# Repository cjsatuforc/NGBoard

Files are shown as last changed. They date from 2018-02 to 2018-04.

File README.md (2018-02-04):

# NGBoard
Next generation 3d printer controller board
## TODO
* Development
  * PCB Layout
  * BOM/Parts list
  * Switching regulator test
* Production
  * Software
  * Testing
* Profit

## Features
* 32 bit microcontroller (STM32F401VET)
* Trinamic tmc2130 drivers
* Raspberry pi/orange pi connector
* 12V or 24V 
* Direct connect inductive sensor

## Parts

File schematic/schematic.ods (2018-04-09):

Source: | /media/data/Git/NGBoard/schematic/schematic.sch
Date: | Sun 04 Feb 2018 08:46:15 PM CET
Tool: | Eeschema 4.0.7+dfsg1-1
Generator: | /usr/lib/kicad/plugins/bom_csv_grouped_by_value_with_fp.py
Component Count: | 263
Ref | Qnty | Value | RS | Price |  | Cmp name | Footprint | Description | Vendor
C1, C9, C7, C10, C14, C11, C12, C23, C21, C24, C28, C25, C26, C37, C35, C38, C42, C39, C40, C51, C49, C52, C56, C53, C54, C63, C66, C70, C62, C65, C71, C64, C67, C75, C78, C76, C79, C77, C80, C93, C94, C95, C96, C97, C98, C99, C106, | 47 | 100nF | 135-8345 | 0.005 | 0.235 | C | Capacitors_SMD:C_0603 | Unpolarized capacitor
C2, C3, C84, | 3 | 18pF | 652-0263 | 0.031 | 0.093 | C | Capacitors_SMD:C_0603 | Unpolarized capacitor
C4, C5, | 2 | 2.2uF | 798-4649 | 0.039 | 0.078 | C | Capacitors_SMD:C_0805 | Unpolarized capacitor
C6, C20, C34, C48, | 4 | 4.7uF | 798-4668 | 0.041 | 0.164 | C | Capacitors_SMD:C_0805 | Unpolarized capacitor
C8, C22, C36, C50, | 4 | 470nF | 652-0904 | 0.029 | 0.116 | C | Capacitors_SMD:C_0603 | Unpolarized capacitor
C13, C27, C41, C55, | 4 | 22n | 698-3276 | 0.031 | 0.124 | C | Capacitors_SMD:C_0603 | Unpolarized capacitor
C15, C29, C43, C57, C69, C68, | 6 | 100uF | 737-9684 | 0.212 | 1.272 | CP | Capacitors_SMD:CP_Elec_8x10 | Polarised capacitor
C16, C17, C19, C18, C30, C31, C33, C32, C44, C45, C47, C46, C58, C59, C61, C60, | 16 | 1nF | 135-6542 | 0.007 | 0.112 | C | Capacitors_SMD:C_0603 | Unpolarized capacitor
C72, C73, C74, | 3 | 10uF | 885-1890 | 0.13 | 0.39 | C | Capacitors_SMD:C_1206 | Unpolarized capacitor
C81, C82, C83, | 3 | 6800pF | 135-6555 | 0.007 | 0.021 | C | Capacitors_SMD:C_0603 | Unpolarized capacitor
C85, C86, | 2 | 100pF | 264-4523 | 0.022 | 0.044 | C | Capacitors_SMD:C_0603 | Unpolarized capacitor
C87, C90, C88, C91, C89, C92, | 6 | 22uF | 885-1887 | 0.165 | 0.99 | C | Capacitors_SMD:C_1206 | Unpolarized capacitor
C100, C103, C101, C104, C102, C105, | 6 | 1uF | 456-8308 | 0.012 | 0.072 | C | Capacitors_SMD:C_0805 | Unpolarized capacitor
D3, D2, D1, | 3 | SMAJ24A | 748-5161 | 0.105 | 0.315 | D_Schottky | Diodes_SMD:D_SMA | Schottky diode
D4, D5, | 2 | SK310A | 652-6104 | 0.147 | 0.294 | D_Schottky | Diodes_SMD:D_SMA | Schottky diode
D8, D9, D6, D7, | 4 | LED | 692-1170 | 0.037 | 0.148 | LED | LEDs:LED_0805 | LED generic
D10, D11, D15, D13, D14, D12, | 6 | BAT54SW | 380-1216 | 0.08 | 0.48 | D_Schottky_x2_Serial_AKC | TO_SOT_Packages_SMD:SOT-323_SC-70 | Dual schottky diode
D16, | 1 | 3.3V | 687-8250 | 0.087 | 0.087 | D_Zener | Diodes_SMD:D_SOD-123 | Zener Diode
D17, D18, D19, | 3 | D | 700-0861 | 0.029 | 0.087 | D | Diodes_SMD:D_MiniMELF | Diode
F1, | 1 | 15A | 167-6068 | 0.91 | 0.91 | Fuse | Fuse_Holders_and_Fuses:BladeFuse-CarType | Fuse, generic
F3, F2, | 2 | 5A | 167-6068 | 0.91 | 1.82 | Fuse | Fuse_Holders_and_Fuses:BladeFuse-CarType | Fuse, generic
J1, J2, J3, J5, J4, J17, | 6 | Conn_01x04 |  |  | 0 | Conn_01x04 | Socket_Strips:Socket_Strip_Straight_1x04_Pitch2.54mm | Generic connector, single row, 01x04
J6, | 1 | Conn_01x06 | 897-0711 | 0.648 | 0.648 | Conn_01x06 | TerminalBlock_Phoenix:TerminalBlock_Phoenix_MKDS1.5-6pol | Generic connector, single row, 01x06
J7, | 1 | Conn_01x03 |  |  | 0 | Conn_01x03 | Socket_Strips:Socket_Strip_Straight_1x03_Pitch2.54mm | Generic connector, single row, 01x03
J8, | 1 | Screw_Terminal_01x02 | 425-8720 | 0.202 | 0.202 | Screw_Terminal_01x02 | TerminalBlock_Phoenix:TerminalBlock_Phoenix_MKDS1.5-2pol | Generic screw terminal, single row, 01x02
J9, J10, | 2 | Conn_01x03 | 483-8477 | 0.193 | 0.386 | Conn_01x03 | Sockets_MOLEX_KK-System:Socket_MOLEX-KK-RM2-54mm_Lock_3pin_straight | Generic connector, single row, 01x03
J11, J12, J13, J14, J15, J16, | 6 | Conn_01x02 |  |  | 0 | Conn_01x02 | Socket_Strips:Socket_Strip_Straight_1x02_Pitch2.54mm | Generic connector, single row, 01x02
J18, | 1 | Conn_02x13_Odd_Even |  |  | 0 | Conn_02x13_Odd_Even | Socket_Strips:Socket_Strip_Straight_2x13_Pitch2.54mm | Generic connector, double row, 02x13, odd/even pin numbering scheme (row 1 odd numbers, row 2 even numbers)
J20, J19, | 2 | Conn_02x05_Odd_Even |  |  | 0 | Conn_02x05_Odd_Even | Connectors:IDC_Header_Straight_10pins | Generic connector, double row, 02x05, odd/even pin numbering scheme (row 1 odd numbers, row 2 even numbers)
J21, | 1 | Conn_02x05_Odd_Even |  |  | 0 | Conn_02x05_Odd_Even | Pin_Headers:Pin_Header_Straight_2x05_Pitch2.54mm | Generic connector, double row, 02x05, odd/even pin numbering scheme (row 1 odd numbers, row 2 even numbers)
L1, L2, L4, L3, L5, L6, L8, L7, L9, L10, L12, L11, L13, L14, L16, L15, | 16 | 120R | 747-4710 | 0.031 | 0.496 | Ferrite_Bead_Small | Inductors_SMD:L_0603 | Ferrite bead, small symbol
L18, L17, | 2 | 60R | 188-8665 | 0.203 | 0.406 | L_Core_Ferrite | Inductors_SMD:L_1806 | Inductor with Ferrite Core
L19, | 1 | 4.7uH | 743-5116 | 0.282 | 0.282 | L | Inductors_SMD_GITHUB:L_Wuerth_HCM-7070 | Inductor
L20, L21, | 2 | 3.3uH | 743-5107 | 0.271 | 0.542 | L | Inductors_SMD_GITHUB:L_Wuerth_HCM-7070 | Inductor
MK1, MK3, MK2, MK4, | 4 | Mounting_Hole | N/A | 0 | 0 | Mounting_Hole | Mounting_Holes:MountingHole_3.2mm_M3 | Mounting Hole without connection
Q1, Q2, | 2 | PSMN1R7-30YL | 798-2912 | 0.6 | 1.2 | PSMN1 | TO_SOT_Packages_SMD:SOT-669_LFPAK_ThermalVias-1 | Transistor N-MOSFET (general)
Q3, Q4, | 2 | NCV8402 | 807-9956 | 0.41 | 0.82 | Q_NMOS_GDSD | TO_SOT_Packages_SMD:SOT-223 | Transistor N-MOSFETwith substrate diode, drain connected to mounting plane (general)
R1, R2, R4, R3, R8, R7, R12, R11, R16, R15, R26, R27, R58, R59, R60, R65, R72, R73, R74, | 19 | 10K | 125-1173 | 0.015 | 0.285 | R | Resistors_SMD:R_0603 | Resistor
R5, R6, R9, R10, R13, R14, R17, R18, | 8 | 0.22 | 740-9173 | 0.138 | 1.104 | R | Resistors_SMD:R_1206 | Resistor
R19, | 1 | 82K | 679-0737 | 0.024 | 0.024 | R | Resistors_SMD:R_0603 | Resistor
R20, R21, | 2 | 24K | 679-0046 | 0.024 | 0.048 | R | Resistors_SMD:R_0603 | Resistor
R22, | 1 | 430K | 679-0374 | 0.015 | 0.015 | R | Resistors_SMD:R_0603 | Resistor
R23, R24, | 2 | 75K | 810-2328 | 0.032 | 0.064 | R | Resistors_SMD:R_0603 | Resistor
R25, | 1 | 15K | 213-2430 | 0.016 | 0.016 | R | Resistors_SMD:R_0603 | Resistor
R34, R35, R28, R29, R55, R56, R57, R64, | 8 | 100 | 901-3525 | 0.004 | 0.032 | R | Resistors_SMD:R_0603 | Resistor
R36, R37, R30, R31, | 4 | 100K | 740-8811 | 0.026 | 0.104 | R | Resistors_SMD:R_0603 | Resistor
R38, R44, R39, R45, R32, R33, | 6 | 1.8K | 901-3569 | 0.004 | 0.024 | R | Resistors_SMD:R_0603 | Resistor
R40, R42, R41, R43, | 4 | 1K | 213-2266 | 0.008 | 0.032 | R | Resistors_SMD:R_0603 | Resistor
R46, R49, R47, R50, R48, R51, R61, R62, | 8 | 2K37 | 679-0131 | 0.016 | 0.128 | R | Resistors_SMD:R_0603 | Resistor
R52, R53, R54, R63, | 4 | 4.7K | 901-3581 | 0.004 | 0.016 | R | Resistors_SMD:R_0603 | Resistor
R66, R69, R67, R70, R68, R71, | 6 | 1.6K | 873-9309 | 0.024 | 0.144 | R | Resistors_SMD:R_0603 | Resistor
SW1, | 1 | SW_Push_Dual | 135-9534 | 0.105 | 0.105 | SW_Push_Dual | Buttons_Switches_THT:SW_TH_Tactile_Omron_B3F-10xx | Push button switch, generic, symbol, four pins
SW2, | 1 | SW_DIP_x03 | 161-4064 | 0.253 | 0.253 | SW_DIP_x03 | Buttons_Switches_THT:SW_DIP_x3_W7.62mm_Slide | 3x DIP Switch, Single Pole Single Throw (SPST) switch, small symbol
U1, | 1 | STM32F401VETx | 497-17430-ND | 6.16 | 6.16 | STM32F401VETx | Housings_QFP:TQFP-100_14x14mm_Pitch0.5mm | Core: ARM Cortex-M4 Package: LQFP100 Flash: 384KB Ram: 96KB Frequency: 84MHz Voltage: 1.7..3.6V IO-pins: 81
U2, U3, U4, U5, | 4 | TMC2130 | 1460-1186-1-ND | 3.869 | 15.476 | TMC2130 | tmc2130:TQFP-48-1EP_7x7mm_Pitch0.5mm | Driver for two-phase stepper motors with external mosfet
U6, U7, U8, | 3 | BD9E302EFJ | 128-8893 | 0.778 | 2.334 | BD9E302EFJ | HTSOP-J8:SOIC-8
Y1, | 1 | Crystal_GND24 | 904-7437 | 0.31 | 0.31 | Crystal_GND24 | Crystals:Crystal_SMD_SeikoEpson_FA238-4pin_3.2x2.5mm_HandSoldering | Four pin crystal (GND on pins 2 and 4), e.g. in SMD package
 |  |  |  | Total | 36.8272
 |  |  |  | Total + Tax | 44.560912

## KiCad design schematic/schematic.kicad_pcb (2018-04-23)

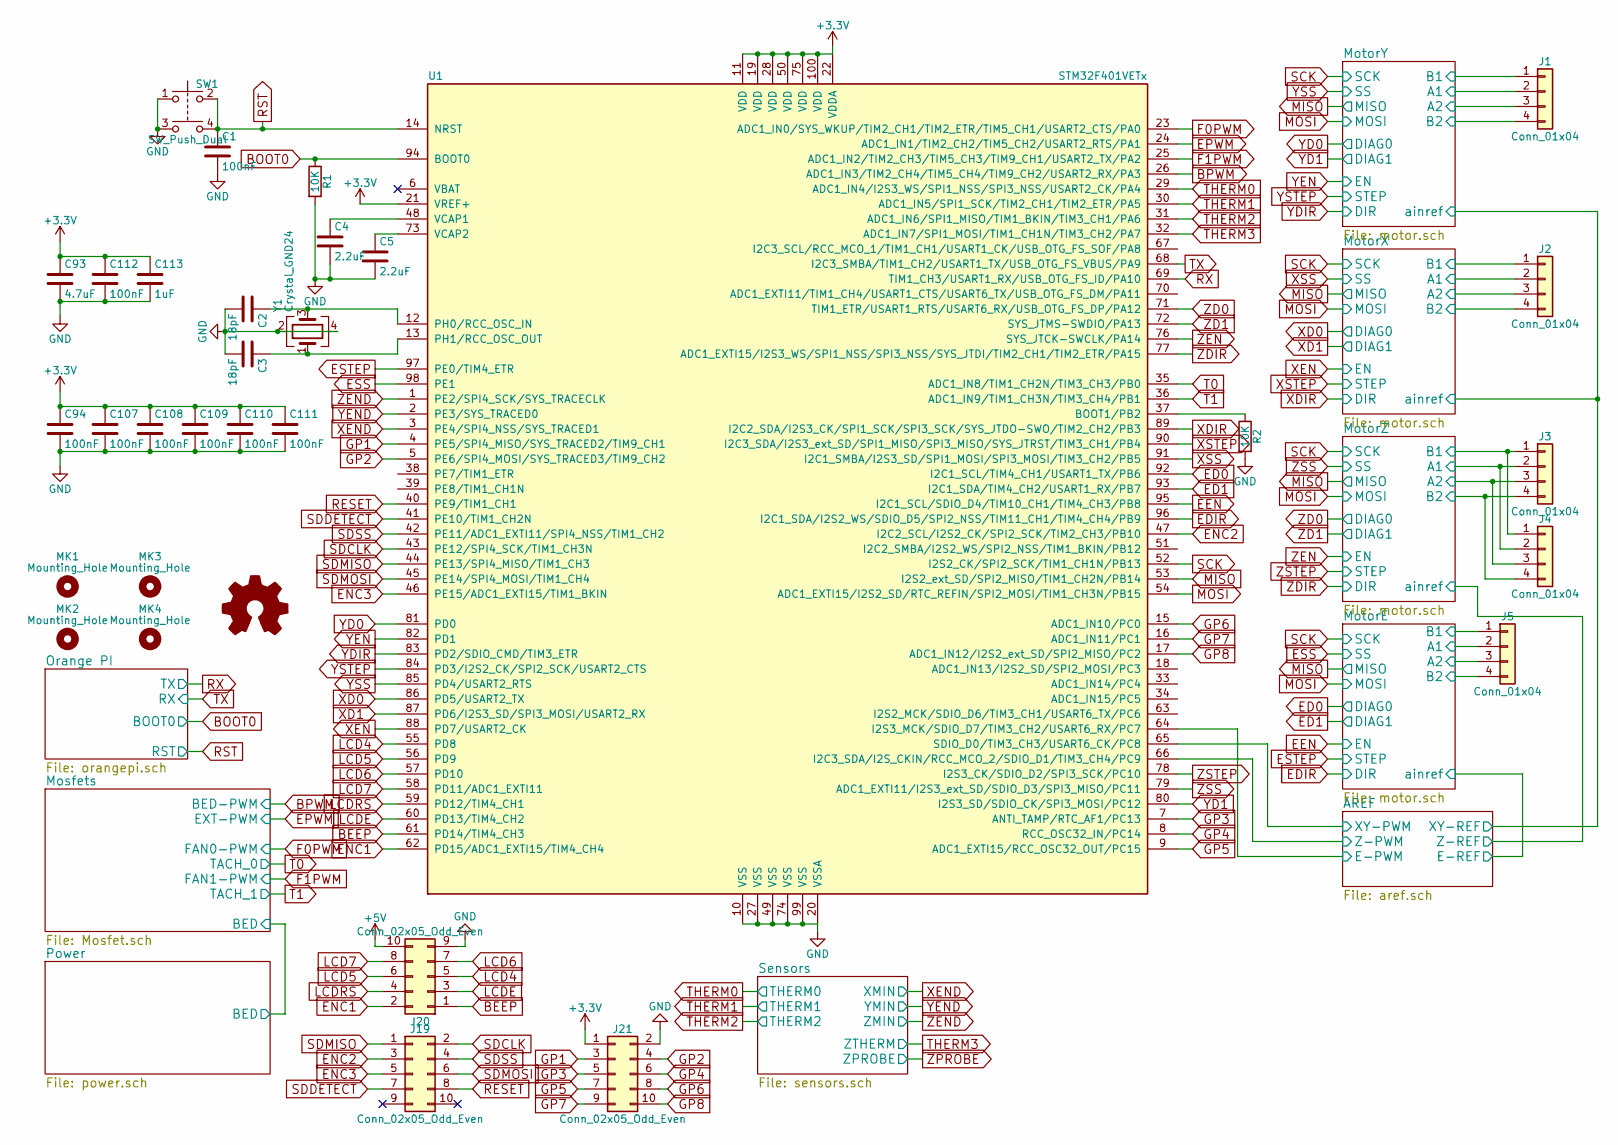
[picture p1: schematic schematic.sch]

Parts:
C1, C107, C108, C109, C110, C111, C112: 100nF; C_0603
C2, C3: 18pF; C_0603
C4, C5: 2.2uF; C_0805
C93: 4.7uF; C_0603
C94: 100nF; C_0603_1608Metric
C113: 1uF; C_0603
J1, J2, J3, J4, J5: Conn_01x04; Socket_Strip_Straight_1x04_Pitch2.54mm
J19, J20: Conn_02x05_Odd_Even; IDC_Header_Straight_10pins
J21: Conn_02x05_Odd_Even; Pin_Header_Straight_2x05_Pitch2.54mm
MK1, MK2, MK3, MK4: Mounting_Hole; MountingHole_3.2mm_M3
R1, R2: 10K; R_0603
SW1: SW_Push_Dual; SW_TH_Tactile_Omron_B3F-10xx
U1: STM32F401VETx; TQFP-100_14x14mm_Pitch0.5mm
Y1: Crystal_GND24; Crystal_SMD_SeikoEpson_FA238-4pin_3.2x2.5mm_HandSoldering

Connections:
+3V3: C93.1, C94.1, C107.1, C108.1, C109.1, C110.1, C111.1, C112.1, C113.1, J21.1, U1.11 (VDD), U1.19 (VDD), U1.21 (VREF+), U1.22 (VDDA), U1.28 (VDD), U1.50 (VDD), U1.75 (VDD), U1.100 (VDD); also elsewhere on the board
+5V: J20.10; also elsewhere on the board
/AREF/E-PWM: U1.64 (I2S3_MCK/SDIO_D7/TIM3_CH2/USART6_RX/PC7); also elsewhere on the board
/AREF/XY-PWM: U1.65 (SDIO_D0/TIM3_CH3/USART6_CK/PC8); also elsewhere on the board
/AREF/Z-PWM: U1.66 (I2C3_SDA/I2S_CKIN/RCC_MCO_2/SDIO_D1/TIM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); also elsewhere on the board
/MotorE/A1: J5.2; also elsewhere on the board
/MotorE/A2: J5.3; also elsewhere on the board
/MotorE/B1: J5.1; also elsewhere on the board
/MotorE/B2: J5.4; also elsewhere on the board
/MotorX/A1: J2.2; also elsewhere on the board
/MotorX/A2: J2.3; also elsewhere on the board
/MotorX/B1: J2.1; also elsewhere on the board
/MotorX/B2: J2.4; also elsewhere on the board
/MotorY/A1: J1.2; also elsewhere on the board
/MotorY/A2: J1.3; also elsewhere on the board
/MotorY/B1: J1.1; also elsewhere on the board
/MotorY/B2: J1.4; also elsewhere on the board
/MotorZ/A1: J3.2, J4.2; also elsewhere on the board
/MotorZ/A2: J3.3, J4.3; also elsewhere on the board
/MotorZ/B1: J3.1, J4.1; also elsewhere on the board
/MotorZ/B2: J3.4, J4.4; also elsewhere on the board
BEEP: J20.1, U1.61 (PD14/TIM4_CH3)
BOOT0: R1.1, U1.94 (BOOT0); also elsewhere on the board
BPWM: U1.26 (ADC1_IN3/TIM2_CH4/TIM5_CH4/TIM9_CH2/USA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); also elsewhere on the board
ED0: U1.92 (I2C1_SCL/TIM4_CH1/USART1_TX/PB6); also elsewhere on the board
ED1: U1.93 (I2C1_SDA/TIM4_CH2/USART1_RX/PB7); also elsewhere on the board
EDIR: U1.96 (I2C1_SDA/I2S2_WS/SDIO_D5/SPI2_NSS/TIM11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); also elsewhere on the board
EEN: U1.95 (I2C1_SCL/SDIO_D4/TIM10_CH1/TIM4_CH3/PB8); also elsewhere on the board
ENC1: J20.2, U1.62 (PD15/ADC1_EXTI15/TIM4_CH4)
ENC2: J19.3, U1.47 (I2C2_SCL/I2S2_CK/SPI2_SCK/TIM2_CH3/PB10)
ENC3: J19.5, U1.46 (PE15/ADC1_EXTI15/TIM1_BKIN)
EPWM: U1.24 (ADC1_IN1/TIM2_CH2/TIM5_CH2/USART2_RTS/P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); also elsewhere on the board
ESS: U1.98 (PE1); also elsewhere on the board
ESTEP: U1.97 (PE0/TIM4_ETR); also elsewhere on the board
F0PWM: U1.23 (ADC1_IN0/SYS_WKUP/TIM2_CH1/TIM2_ETR/TIM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); also elsewhere on the board
F1PWM: U1.25 (ADC1_IN2/TIM2_CH3/TIM5_CH3/TIM9_CH1/USA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); also elsewhere on the board
GND: C1.2, C2.2, C3.2, C4.2, C5.2, C93.2, C94.2, C107.2, C108.2, C109.2, C110.2, C111.2, C112.2, C113.2, J20.9, J21.2, R1.2, R2.2, SW1.1, SW1.3, U1.10 (VSS), U1.20 (VSSA), U1.27 (VSS), U1.49 (VSS), U1.74 (VSS), U1.99 (VSS), Y1.2, Y1.4; also elsewhere on the board
GP1: J21.3, U1.4 (PE5/SPI4_MISO/SYS_TRACED2/TIM9_CH1)
GP2: J21.4, U1.5 (PE6/SPI4_MOSI/SYS_TRACED3/TIM9_CH2)
GP3: J21.5, U1.7 (ANTI_TAMP/RTC_AF1/PC13)
GP4: J21.6, U1.8 (RCC_OSC32_IN/PC14)
GP5: J21.7, U1.9 (ADC1_EXTI15/RCC_OSC32_OUT/PC15)
GP6: J21.8, U1.15 (ADC1_IN10/PC0)
GP7: J21.9, U1.16 (ADC1_IN11/PC1)
GP8: J21.10, U1.17 (ADC1_IN12/I2S2_ext_SD/SPI2_MISO/PC2)
LCD4: J20.5, U1.55 (PD8)
LCD5: J20.6, U1.56 (PD9)
LCD6: J20.7, U1.57 (PD10)
LCD7: J20.8, U1.58 (PD11/ADC1_EXTI11)
LCDE: J20.3, U1.60 (PD13/TIM4_CH2)
LCDRS: J20.4, U1.59 (PD12/TIM4_CH1)
MISO: U1.53 (I2S2_ext_SD/SPI2_MISO/TIM1_CH2N/PB14); also elsewhere on the board
MOSI: U1.54 (ADC1_EXTI15/I2S2_SD/RTC_REFIN/SPI2_MOSI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); also elsewhere on the board
unnamed: C2.1, U1.12 (PH0/RCC_OSC_IN), Y1.3
unnamed: C3.1, U1.13 (PH1/RCC_OSC_OUT), Y1.1
unnamed: C4.1, U1.48 (VCAP1)
unnamed: C5.1, U1.73 (VCAP2)
unnamed: R2.1, U1.37 (BOOT1/PB2)
RESET: J19.8, U1.40 (PE9/TIM1_CH1)
RST: C1.1, SW1.2, SW1.4, U1.14 (NRST); also elsewhere on the board
RX: U1.69 (TIM1_CH3/USART1_RX/USB_OTG_FS_ID/PA10); also elsewhere on the board
SCK: U1.52 (I2S2_CK/SPI2_SCK/TIM1_CH1N/PB13); also elsewhere on the board
SDCLK: J19.2, U1.43 (PE12/SPI4_SCK/TIM1_CH3N)
SDDETECT: J19.7, U1.41 (PE10/TIM1_CH2N)
SDMISO: J19.1, U1.44 (PE13/SPI4_MISO/TIM1_CH3)
SDMOSI: J19.6, U1.45 (PE14/SPI4_MOSI/TIM1_CH4)
SDSS: J19.4, U1.42 (PE11/ADC1_EXTI11/SPI4_NSS/TIM1_CH2)
T0: U1.35 (ADC1_IN8/TIM1_CH2N/TIM3_CH3/PB0); also elsewhere on the board
T1: U1.36 (ADC1_IN9/TIM1_CH3N/TIM3_CH4/PB1); also elsewhere on the board
THERM0: U1.29 (ADC1_IN4/I2S3_WS/SPI1_NSS/SPI3_NSS/USAR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); also elsewhere on the board
THERM1: U1.30 (ADC1_IN5/SPI1_SCK/TIM2_CH1/TIM2_ETR/PA5); also elsewhere on the board
THERM2: U1.31 (ADC1_IN6/SPI1_MISO/TIM1_BKIN/TIM3_CH1/P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); also elsewhere on the board
THERM3: U1.32 (ADC1_IN7/SPI1_MOSI/TIM1_CH1N/TIM3_CH2/P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); also elsewhere on the board
TX: U1.68 (I2C3_SMBA/TIM1_CH2/USART1_TX/USB_OTG_FS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); also elsewhere on the board
XD0: U1.86 (PD5/USART2_TX); also elsewhere on the board
XD1: U1.87 (PD6/I2S3_SD/SPI3_MOSI/USART2_RX); also elsewhere on the board
XDIR: U1.89 (I2C2_SDA/I2S3_CK/SPI1_SCK/SPI3_SCK/SYS_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); also elsewhere on the board
XEN: U1.88 (PD7/USART2_CK); also elsewhere on the board
XEND: U1.3 (PE4/SPI4_NSS/SYS_TRACED1); also elsewhere on the board
XSS: U1.91 (I2C1_SMBA/I2S3_SD/SPI1_MOSI/SPI3_MOSI/T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); also elsewhere on the board
XSTEP: U1.90 (I2C3_SDA/I2S3_ext_SD/SPI1_MISO/SPI3_MIS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); also elsewhere on the board
YD0: U1.81 (PD0); also elsewhere on the board
YD1: U1.80 (I2S3_SD/SDIO_CK/SPI3_MOSI/PC12); also elsewhere on the board
YDIR: U1.83 (PD2/SDIO_CMD/TIM3_ETR); also elsewhere on the board
YEN: U1.82 (PD1); also elsewhere on the board
YEND: U1.2 (PE3/SYS_TRACED0); also elsewhere on the board
YSS: U1.85 (PD4/USART2_RTS); also elsewhere on the board
YSTEP: U1.84 (PD3/I2S2_CK/SPI2_SCK/USART2_CTS); also elsewhere on the board
ZD0: U1.71 (TIM1_ETR/USART1_RTS/USART6_RX/USB_OTG_F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); also elsewhere on the board
ZD1: U1.72 (SYS_JTMS-SWDIO/PA13); also elsewhere on the board
ZDIR: U1.77 (ADC1_EXTI15/I2S3_WS/SPI1_NSS/SPI3_NSS/S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); also elsewhere on the board
ZEN: U1.76 (SYS_JTCK-SWCLK/PA14); also elsewhere on the board
ZEND: U1.1 (PE2/SPI4_SCK/SYS_TRACECLK); also elsewhere on the board
ZSS: U1.79 (ADC1_EXTI11/I2S3_ext_SD/SDIO_D3/SPI3_MI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); also elsewhere on the board
ZSTEP: U1.78 (I2S3_CK/SDIO_D2/SPI3_SCK/PC10); also elsewhere on the board

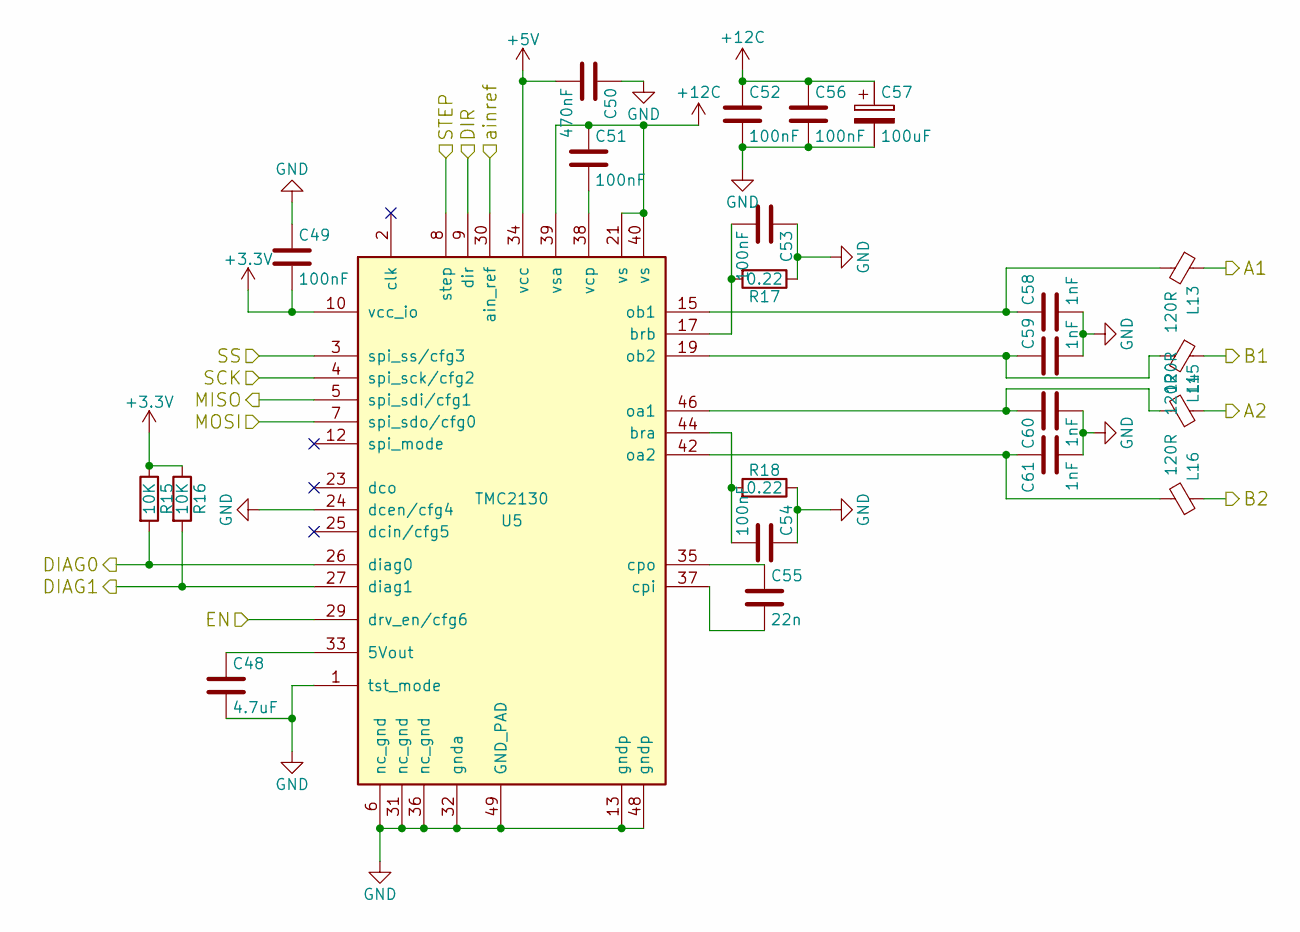
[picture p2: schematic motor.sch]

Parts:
C6: 4.7uF; C_0805
C7, C9, C10, C11, C12, C14: 100nF; C_0603
C8: 470nF; C_0603
C13: 22n; C_0603; Voltage 63V
C15: 100uF; CP_Elec_8x10
C16, C17, C18, C19: 1nF; C_0603
L1, L2, L3, L4: 120R; L_0603
R3, R4: 10K; R_0603
R5, R6: 0.22; R_1206
U2: TMC2130; TQFP-48-1EP_7x7mm_Pitch0.5mm

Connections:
+3V3: C7.2, R3.1, R4.1, U2.10 (vcc_io); also elsewhere on the board
+5V: C8.2, U2.34 (vcc); also elsewhere on the board
+12C: C9.1, C10.1, C14.1, C15.1, U2.21 (vs), U2.39 (vsa), U2.40 (vs); also elsewhere on the board
/AREF/XY-REF: U2.30 (ain_ref); also elsewhere on the board
/MotorX/A1: L1.1; also elsewhere on the board
/MotorX/A2: L3.1; also elsewhere on the board
/MotorX/B1: L2.1; also elsewhere on the board
/MotorX/B2: L4.1; also elsewhere on the board
GND: C6.2, C7.1, C8.1, C10.2, C11.1, C12.1, C14.2, C15.2, C16.2, C17.2, C18.2, C19.2, R5.1, R6.1, U2.1 (tst_mode), U2.6 (nc_gnd), U2.13 (gndp), U2.24 (dcen/cfg4), U2.31 (nc_gnd), U2.32 (gnda), U2.36 (nc_gnd), U2.48 (gndp), U2.49 (GND_PAD); also elsewhere on the board
MISO: U2.5 (spi_sdi/cfg1); also elsewhere on the board
MOSI: U2.7 (spi_sdo/cfg0); also elsewhere on the board
unnamed: C6.1, U2.33 (5Vout)
unnamed: C9.2, U2.38 (vcp)
unnamed: C11.2, R5.2, U2.17 (brb)
unnamed: C12.2, R6.2, U2.44 (bra)
unnamed: C13.1, U2.35 (cpo)
unnamed: C13.2, U2.37 (cpi)
unnamed: C16.1, L1.2, U2.15 (ob1)
unnamed: C17.1, L2.2, U2.19 (ob2)
unnamed: C18.1, L3.2, U2.46 (oa1)
unnamed: C19.1, L4.2, U2.42 (oa2)
SCK: U2.4 (spi_sck/cfg2); also elsewhere on the board
XD0: R3.2, U2.26 (diag0); also elsewhere on the board
XD1: R4.2, U2.27 (diag1); also elsewhere on the board
XDIR: U2.9 (dir); also elsewhere on the board
XEN: U2.29 (drv_en/cfg6); also elsewhere on the board
XSS: U2.3 (spi_ss/cfg3); also elsewhere on the board
XSTEP: U2.8 (step); also elsewhere on the board

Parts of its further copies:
C20, C34, C48: 4.7uF; C_0805
C21, C23, C24, C25, C26, C28, C35, C37, C38, C39, C40, C42, C49, C51, C52, C53, C54, C56: 100nF; C_0603
C22, C36, C50: 470nF; C_0603
C27, C41, C55: 22n; C_0603; Voltage 63V
C29, C43, C57: 100uF; CP_Elec_8x10
C30, C31, C32, C33, C44, C45, C46, C47, C58, C59, C60, C61: 1nF; C_0603
L5, L6, L7, L8, L9, L10, L11, L12, L13, L14, L15, L16: 120R; L_0603
R7, R8, R11, R12, R15, R16: 10K; R_0603
R9, R10, R13, R14, R17, R18: 0.22; R_1206
U3, U4, U5: TMC2130; TQFP-48-1EP_7x7mm_Pitch0.5mm

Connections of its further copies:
+3V3: C21.2, C35.2, C49.2, R7.1, R8.1, R11.1, R12.1, R15.1, R16.1, U3.10 (vcc_io), U4.10 (vcc_io), U5.10 (vcc_io); also elsewhere on the board
+5V: C22.2, C36.2, C50.2, U3.34 (vcc), U4.34 (vcc), U5.34 (vcc); also elsewhere on the board
+12C: C23.1, C24.1, C28.1, C29.1, C37.1, C38.1, C42.1, C43.1, C51.1, C52.1, C56.1, C57.1, U3.21 (vs), U3.39 (vsa), U3.40 (vs), U4.21 (vs), U4.39 (vsa), U4.40 (vs), U5.21 (vs), U5.39 (vsa), U5.40 (vs); also elsewhere on the board
/AREF/E-REF: U5.30 (ain_ref); also elsewhere on the board
/AREF/XY-REF: U3.30 (ain_ref); also elsewhere on the board
/AREF/Z-REF: U4.30 (ain_ref); also elsewhere on the board
/MotorE/A1: L13.1; also elsewhere on the board
/MotorE/A2: L15.1; also elsewhere on the board
/MotorE/B1: L14.1; also elsewhere on the board
/MotorE/B2: L16.1; also elsewhere on the board
/MotorY/A1: L5.1; also elsewhere on the board
/MotorY/A2: L7.1; also elsewhere on the board
/MotorY/B1: L6.1; also elsewhere on the board
/MotorY/B2: L8.1; also elsewhere on the board
/MotorZ/A1: L9.1; also elsewhere on the board
/MotorZ/A2: L11.1; also elsewhere on the board
/MotorZ/B1: L10.1; also elsewhere on the board
/MotorZ/B2: L12.1; also elsewhere on the board
ED0: R15.2, U5.26 (diag0); also elsewhere on the board
ED1: R16.2, U5.27 (diag1); also elsewhere on the board
EDIR: U5.9 (dir); also elsewhere on the board
EEN: U5.29 (drv_en/cfg6); also elsewhere on the board
ESS: U5.3 (spi_ss/cfg3); also elsewhere on the board
ESTEP: U5.8 (step); also elsewhere on the board
GND: C20.2, C21.1, C22.1, C24.2, C25.1, C26.1, C28.2, C29.2, C30.2, C31.2, C32.2, C33.2, C34.2, C35.1, C36.1, C38.2, C39.1, C40.1, C42.2, C43.2, C44.2, C45.2, C46.2, C47.2, C48.2, C49.1, C50.1, C52.2, C53.1, C54.1, C56.2, C57.2, C58.2, C59.2, C60.2, C61.2, R9.1, R10.1, R13.1, R14.1, R17.1, R18.1, U3.1 (tst_mode), U3.6 (nc_gnd), U3.13 (gndp), U3.24 (dcen/cfg4), U3.31 (nc_gnd), U3.32 (gnda), U3.36 (nc_gnd), U3.48 (gndp), U3.49 (GND_PAD), U4.1 (tst_mode), U4.6 (nc_gnd), U4.13 (gndp), U4.24 (dcen/cfg4), U4.31 (nc_gnd), U4.32 (gnda), U4.36 (nc_gnd), U4.48 (gndp), U4.49 (GND_PAD), U5.1 (tst_mode), U5.6 (nc_gnd), U5.13 (gndp), U5.24 (dcen/cfg4), U5.31 (nc_gnd), U5.32 (gnda), U5.36 (nc_gnd), U5.48 (gndp), U5.49 (GND_PAD); also elsewhere on the board
MISO: U3.5 (spi_sdi/cfg1), U4.5 (spi_sdi/cfg1), U5.5 (spi_sdi/cfg1); also elsewhere on the board
MOSI: U3.7 (spi_sdo/cfg0), U4.7 (spi_sdo/cfg0), U5.7 (spi_sdo/cfg0); also elsewhere on the board
unnamed: C20.1, U3.33 (5Vout)
unnamed: C23.2, U3.38 (vcp)
unnamed: C25.2, R9.2, U3.17 (brb)
unnamed: C26.2, R10.2, U3.44 (bra)
unnamed: C27.1, U3.35 (cpo)
unnamed: C27.2, U3.37 (cpi)
unnamed: C30.1, L5.2, U3.15 (ob1)
unnamed: C31.1, L6.2, U3.19 (ob2)
unnamed: C32.1, L7.2, U3.46 (oa1)
unnamed: C33.1, L8.2, U3.42 (oa2)
unnamed: C34.1, U4.33 (5Vout)
unnamed: C37.2, U4.38 (vcp)
unnamed: C39.2, R13.2, U4.17 (brb)
unnamed: C40.2, R14.2, U4.44 (bra)
unnamed: C41.1, U4.35 (cpo)
unnamed: C41.2, U4.37 (cpi)
unnamed: C44.1, L9.2, U4.15 (ob1)
unnamed: C45.1, L10.2, U4.19 (ob2)
unnamed: C46.1, L11.2, U4.46 (oa1)
unnamed: C47.1, L12.2, U4.42 (oa2)
unnamed: C48.1, U5.33 (5Vout)
unnamed: C51.2, U5.38 (vcp)
unnamed: C53.2, R17.2, U5.17 (brb)
unnamed: C54.2, R18.2, U5.44 (bra)
unnamed: C55.1, U5.35 (cpo)
unnamed: C55.2, U5.37 (cpi)
unnamed: C58.1, L13.2, U5.15 (ob1)
unnamed: C59.1, L14.2, U5.19 (ob2)
unnamed: C60.1, L15.2, U5.46 (oa1)
unnamed: C61.1, L16.2, U5.42 (oa2)
SCK: U3.4 (spi_sck/cfg2), U4.4 (spi_sck/cfg2), U5.4 (spi_sck/cfg2); also elsewhere on the board
YD0: R7.2, U3.26 (diag0); also elsewhere on the board
YD1: R8.2, U3.27 (diag1); also elsewhere on the board
YDIR: U3.9 (dir); also elsewhere on the board
YEN: U3.29 (drv_en/cfg6); also elsewhere on the board
YSS: U3.3 (spi_ss/cfg3); also elsewhere on the board
YSTEP: U3.8 (step); also elsewhere on the board
ZD0: R11.2, U4.26 (diag0); also elsewhere on the board
ZD1: R12.2, U4.27 (diag1); also elsewhere on the board
ZDIR: U4.9 (dir); also elsewhere on the board
ZEN: U4.29 (drv_en/cfg6); also elsewhere on the board
ZSS: U4.3 (spi_ss/cfg3); also elsewhere on the board
ZSTEP: U4.8 (step); also elsewhere on the board

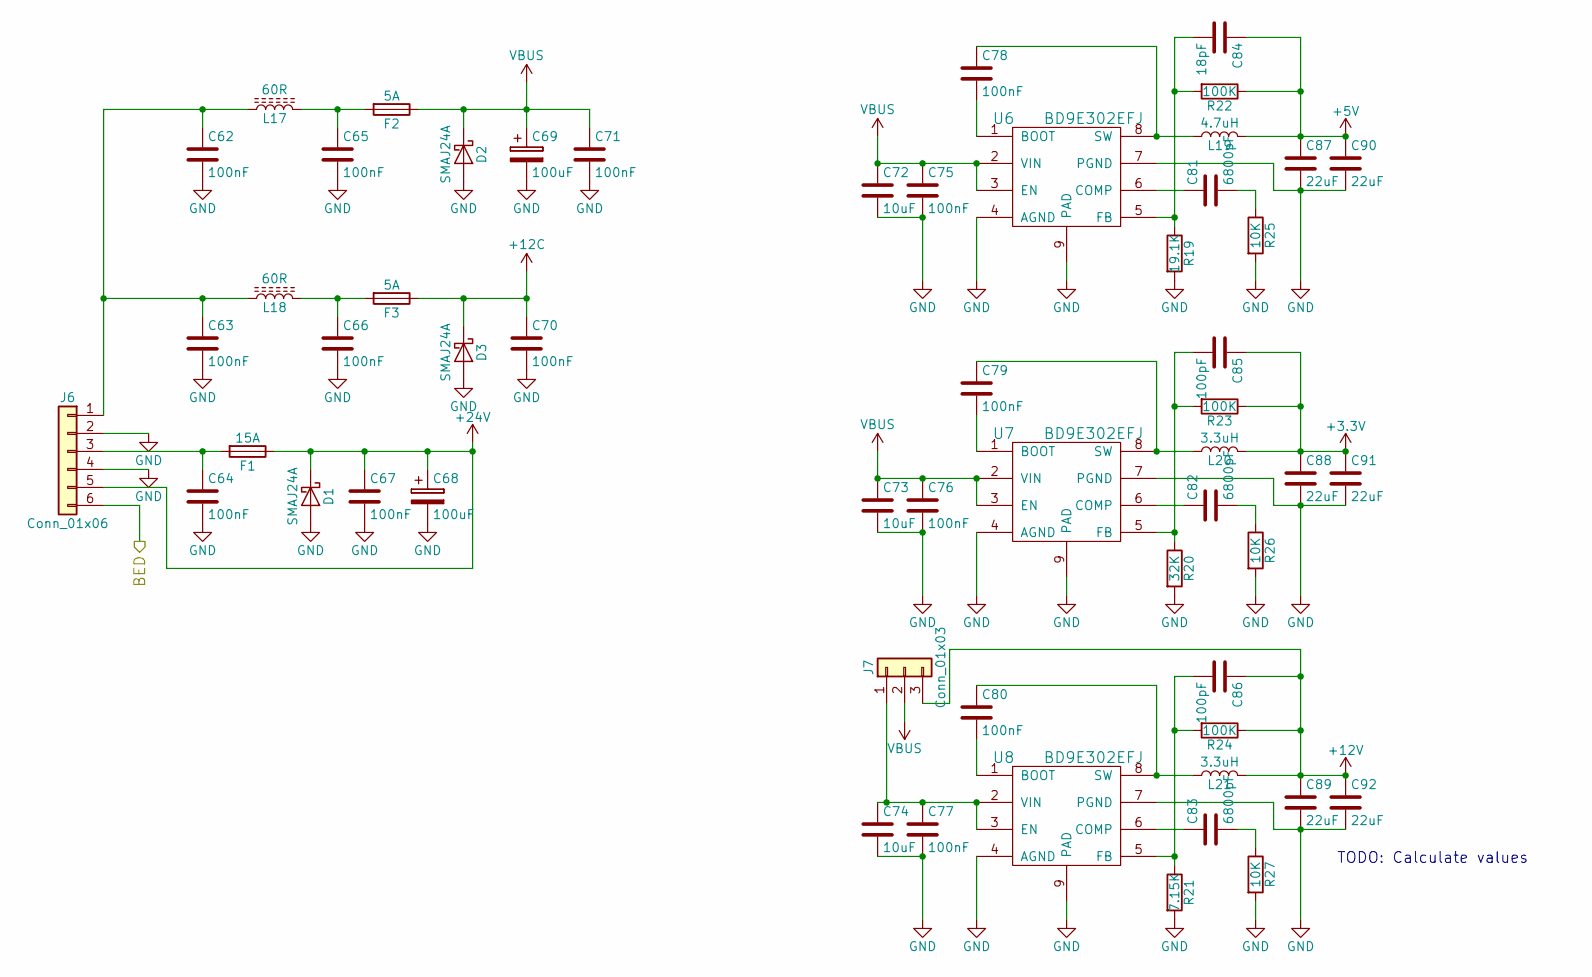
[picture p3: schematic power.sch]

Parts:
C62, C63, C64, C65, C66, C67, C70, C71, C75, C76, C77, C78, C79, C80: 100nF; C_0603
C68, C69: 100uF; CP_Elec_8x10
C72, C73, C74: 10uF; C_1206
C81, C82, C83: 6800pF; C_0603
C84: 18pF; C_0603
C85, C86: 100pF; C_0603
C87, C88, C89, C90, C91, C92: 22uF; C_1206
D1, D2, D3: SMAJ24A; D_SMA
F1: 15A; BladeFuse-CarType
F2, F3: 5A; BladeFuse-CarType
J6: Conn_01x06; TerminalBlock_Phoenix_MKDS1.5-6pol
J7: Conn_01x03; Socket_Strip_Straight_1x03_Pitch2.54mm
L17, L18: 60R; L_1806
L19: 4.7uH; L_Taiyo-Yuden_NR-60xx
L20, L21: 3.3uH; L_Taiyo-Yuden_NR-60xx
R19: 19.1K; R_0603
R20: 32K; R_0603
R21: 7.15K; R_0603
R22, R23, R24: 100K; R_0603
R25, R26, R27: 10K; R_0603
U6, U7, U8: BD9E302EFJ; SOIC-8

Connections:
+3V3: C85.1, C88.1, C91.1, L20.2, R23.1; also elsewhere on the board
+5V: C84.1, C87.1, C90.1, L19.2, R22.1; also elsewhere on the board
+12C: C70.1, D3.1 (K), F3.1; also elsewhere on the board
+12V: C86.1, C89.1, C92.1, J7.3, L21.2, R24.1; also elsewhere on the board
+24V: C67.1, C68.1, D1.1 (K), F1.1, J6.5; also elsewhere on the board
/Mosfets/BED: J6.6; also elsewhere on the board
GND: C62.2, C63.2, C64.2, C65.2, C66.2, C67.2, C68.2, C69.2, C70.2, C71.2, C72.2, C73.2, C74.2, C75.2, C76.2, C77.2, C87.2, C88.2, C89.2, C90.2, C91.2, C92.2, D1.2 (A), D2.2 (A), D3.2 (A), J6.2, J6.4, R19.2, R20.2, R21.2, R25.2, R26.2, R27.2, U6.4 (AGND), U6.7 (PGND), U6.9 (PAD), U7.4 (AGND), U7.7 (PGND), U7.9 (PAD), U8.4 (AGND), U8.7 (PGND), U8.9 (PAD); also elsewhere on the board
unnamed: C62.1, C63.1, J6.1, L17.1, L18.1
unnamed: C64.1, F1.2, J6.3
unnamed: C65.1, F2.2, L17.2
unnamed: C66.1, F3.2, L18.2
unnamed: C74.1, C77.1, J7.1, U8.2 (VIN), U8.3 (EN)
unnamed: C78.1, L19.1, U6.8 (SW)
unnamed: C78.2, U6.1 (BOOT)
unnamed: C79.1, L20.1, U7.8 (SW)
unnamed: C79.2, U7.1 (BOOT)
unnamed: C80.1, L21.1, U8.8 (SW)
unnamed: C80.2, U8.1 (BOOT)
unnamed: C81.1, U6.6 (COMP)
unnamed: C81.2, R25.1
unnamed: C82.1, U7.6 (COMP)
unnamed: C82.2, R26.1
unnamed: C83.1, U8.6 (COMP)
unnamed: C83.2, R27.1
unnamed: C84.2, R19.1, R22.2, U6.5 (FB)
unnamed: C85.2, R20.1, R23.2, U7.5 (FB)
unnamed: C86.2, R21.1, R24.2, U8.5 (FB)
VBUS: C69.1, C71.1, C72.1, C73.1, C75.1, C76.1, D2.1 (K), F2.1, J7.2, U6.2 (VIN), U6.3 (EN), U7.2 (VIN), U7.3 (EN); also elsewhere on the board

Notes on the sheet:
TODO: Calculate values

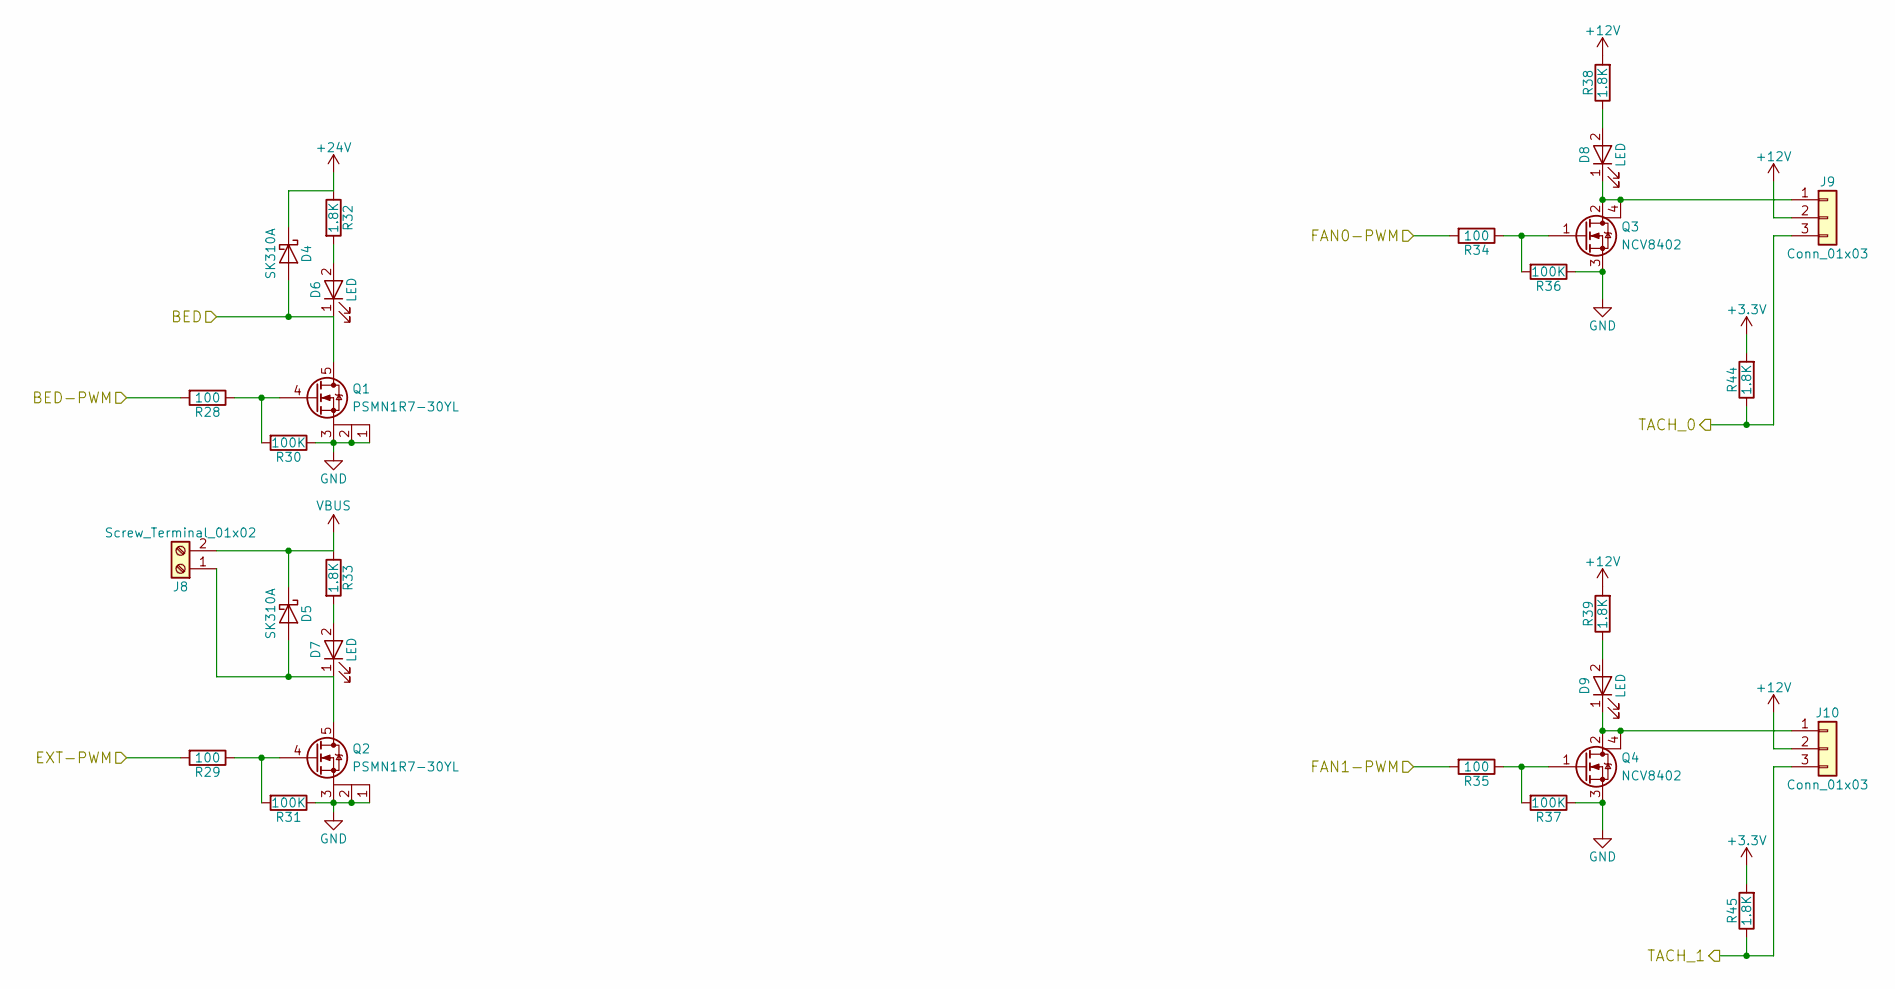
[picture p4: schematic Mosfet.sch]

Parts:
D4, D5: SK310A; D_SMA
D6, D7, D8, D9: LED; LED_0805
J8: Screw_Terminal_01x02; TerminalBlock_Phoenix_MKDS1.5-2pol
J9, J10: Conn_01x03; Socket_MOLEX-KK-RM2-54mm_Lock_3pin_straight
Q1, Q2: PSMN1R7-30YL; SOT-669_LFPAK_ThermalVias-1
Q3, Q4: NCV8402; SOT-223
R28, R29, R34, R35: 100; R_0603
R30, R31, R36, R37: 100K; R_0603
R32, R33, R38, R39, R44, R45: 1.8K; R_0603

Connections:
+3V3: R44.2, R45.2; also elsewhere on the board
+12V: J9.2, J10.2, R38.2, R39.2; also elsewhere on the board
+24V: D4.1 (K), R32.1; also elsewhere on the board
/Mosfets/BED: D4.2 (A), D6.1 (K), Q1.5 (D); also elsewhere on the board
BPWM: R28.2; also elsewhere on the board
EPWM: R29.2; also elsewhere on the board
F0PWM: R34.2; also elsewhere on the board
F1PWM: R35.2; also elsewhere on the board
GND: Q1.1, Q1.2, Q1.3 (S), Q2.1, Q2.2, Q2.3 (S), Q3.3 (S), Q4.3 (S), R30.1, R31.1, R36.1, R37.1; also elsewhere on the board
unnamed: D5.2 (A), D7.1 (K), J8.1, Q2.5 (D)
unnamed: D6.2 (A), R32.2
unnamed: D7.2 (A), R33.2
unnamed: D8.1 (K), J9.1, Q3.2 (D), Q3.4 (D)
unnamed: D8.2 (A), R38.1
unnamed: D9.1 (K), J10.1, Q4.2 (D), Q4.4 (D)
unnamed: D9.2 (A), R39.1
unnamed: Q1.4 (G), R28.1, R30.2
unnamed: Q2.4 (G), R29.1, R31.2
unnamed: Q3.1 (G), R34.1, R36.2
unnamed: Q4.1 (G), R35.1, R37.2
T0: J9.3, R44.1; also elsewhere on the board
T1: J10.3, R45.1; also elsewhere on the board
VBUS: D5.1 (K), J8.2, R33.1; also elsewhere on the board

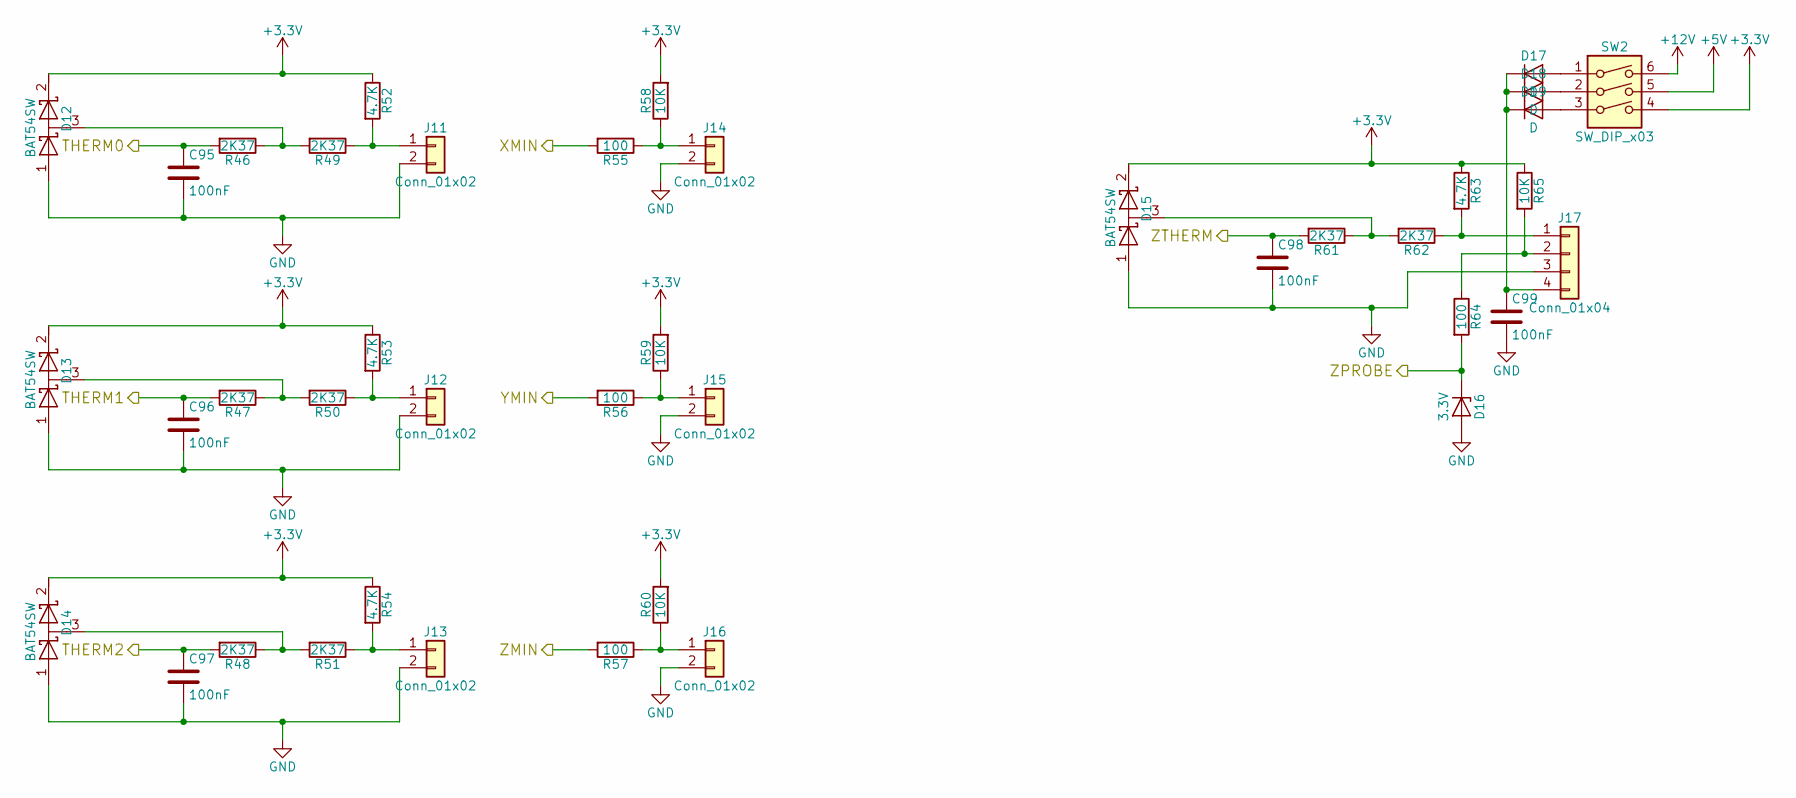
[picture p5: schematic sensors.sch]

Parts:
C95, C96, C97, C98, C99: 100nF; C_0603
D12, D13, D14, D15: BAT54SW; SOT-323_SC-70
D16: 3.3V; D_SOD-123
D17, D18, D19: D; D_MiniMELF
J11, J12, J13, J14, J15, J16: Conn_01x02; Socket_Strip_Straight_1x02_Pitch2.54mm
J17: Conn_01x04; Socket_Strip_Straight_1x04_Pitch2.54mm
R46, R47, R48, R49, R50, R51, R61, R62: 2K37; R_0603
R52, R53, R54, R63: 4.7K; R_0603
R55, R56, R57, R64: 100; R_0603
R58, R59, R60, R65: 10K; R_0603
SW2: SW_DIP_x03; SW_DIP_x3_W7.62mm_Slide

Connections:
+3V3: D12.2 (K), D13.2 (K), D14.2 (K), D15.2 (K), R52.1, R53.1, R54.1, R58.2, R59.2, R60.2, R63.1, R65.1, SW2.4; also elsewhere on the board
+5V: SW2.5; also elsewhere on the board
+12V: SW2.6; also elsewhere on the board
GND: C95.2, C96.2, C97.2, C98.2, C99.2, D12.1 (A), D13.1 (A), D14.1 (A), D15.1 (A), D16.2 (A), J11.2, J12.2, J13.2, J14.2, J15.2, J16.2, J17.3; also elsewhere on the board
unnamed: C99.1, D17.1 (K), D18.1 (K), D19.1 (K), J17.4
unnamed: D12.3 (common), R46.1, R49.2
unnamed: D13.3 (common), R47.1, R50.2
unnamed: D14.3 (common), R48.1, R51.2
unnamed: D15.3 (common), R61.1, R62.2
unnamed: D17.2 (A), SW2.1
unnamed: D18.2 (A), SW2.2
unnamed: D19.2 (A), SW2.3
unnamed: J11.1, R49.1, R52.2
unnamed: J12.1, R50.1, R53.2
unnamed: J13.1, R51.1, R54.2
unnamed: J14.1, R55.1, R58.1
unnamed: J15.1, R56.1, R59.1
unnamed: J16.1, R57.1, R60.1
unnamed: J17.1, R62.1, R63.2
unnamed: J17.2, R64.1, R65.2
THERM0: C95.1, R46.2; also elsewhere on the board
THERM1: C96.1, R47.2; also elsewhere on the board
THERM2: C97.1, R48.2; also elsewhere on the board
THERM3: C98.1, R61.2; also elsewhere on the board
XEND: R55.2; also elsewhere on the board
YEND: R56.2; also elsewhere on the board
ZEND: R57.2; also elsewhere on the board
ZPROBE: D16.1 (K), R64.2

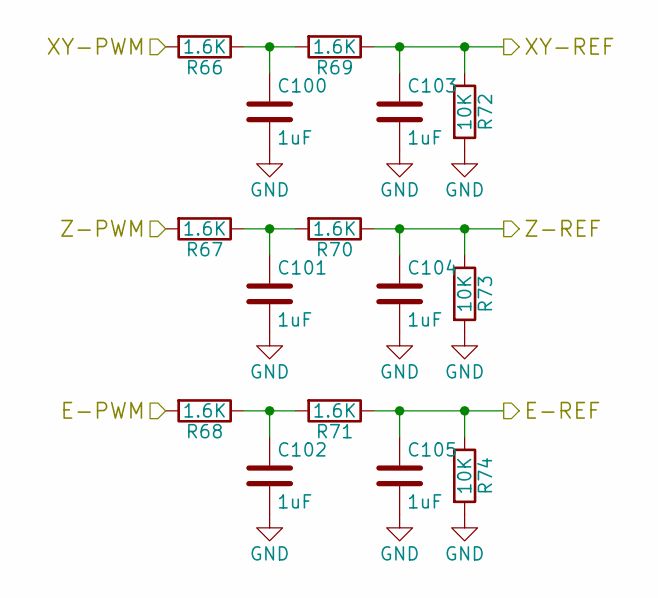
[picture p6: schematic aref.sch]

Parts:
C100, C101, C102, C103, C104, C105: 1uF; C_0805
R66, R67, R68, R69, R70, R71: 1.6K; R_0603
R72, R73, R74: 10K; R_0603

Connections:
/AREF/E-PWM: R68.2; also elsewhere on the board
/AREF/E-REF: C105.1, R71.1, R74.1; also elsewhere on the board
/AREF/XY-PWM: R66.2; also elsewhere on the board
/AREF/XY-REF: C103.1, R69.1, R72.1; also elsewhere on the board
/AREF/Z-PWM: R67.2; also elsewhere on the board
/AREF/Z-REF: C104.1, R70.1, R73.1; also elsewhere on the board
GND: C100.2, C101.2, C102.2, C103.2, C104.2, C105.2, R72.2, R73.2, R74.2; also elsewhere on the board
unnamed: C100.1, R66.1, R69.2
unnamed: C101.1, R67.1, R70.2
unnamed: C102.1, R68.1, R71.2

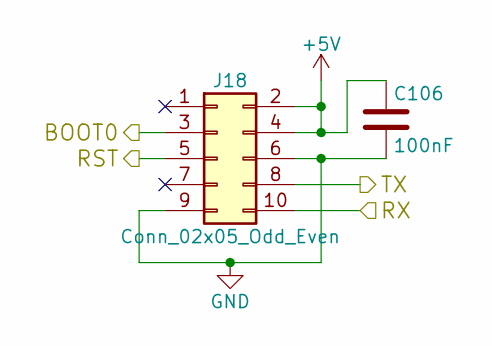
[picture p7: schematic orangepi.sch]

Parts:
C106: 100nF; C_0603
J18: Conn_02x05_Odd_Even; Pin_Header_Straight_2x05_Pitch2.54mm

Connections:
+5V: C106.1, J18.2, J18.4; also elsewhere on the board
BOOT0: J18.3; also elsewhere on the board
GND: C106.2, J18.6, J18.9; also elsewhere on the board
RST: J18.5; also elsewhere on the board
RX: J18.8; also elsewhere on the board
TX: J18.10; also elsewhere on the board

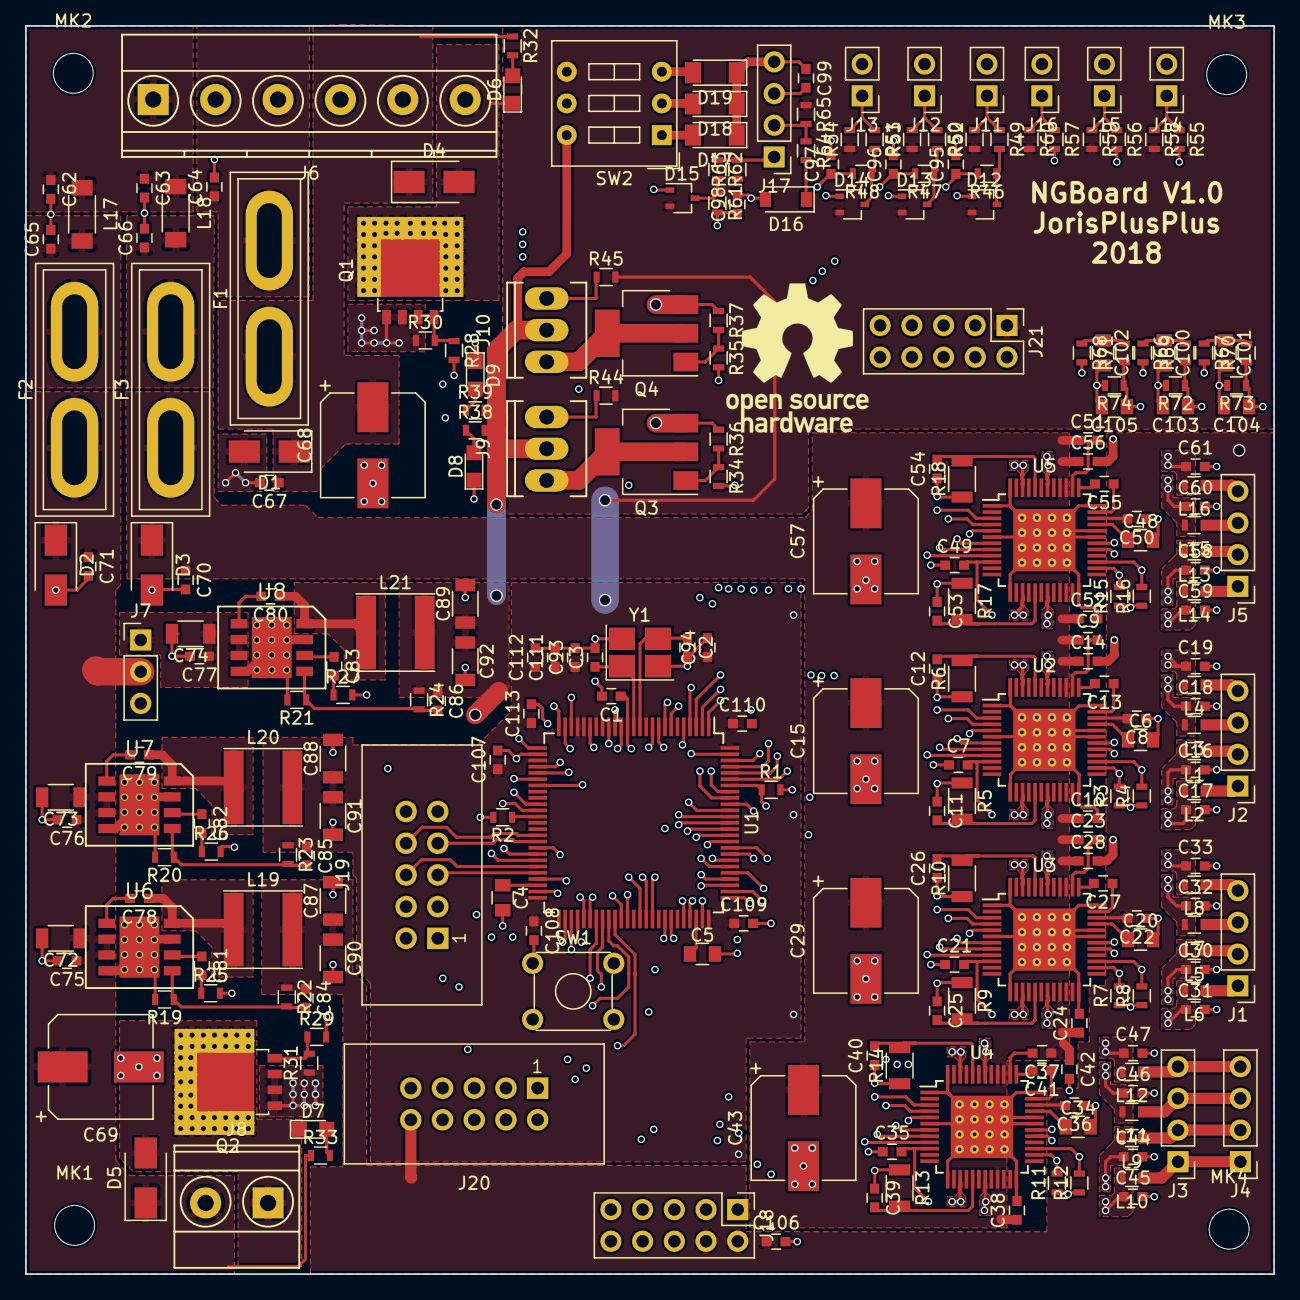
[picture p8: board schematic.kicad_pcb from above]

Board: 4 copper layers, 100.0 x 100.0 mm, 264 parts (0 on the bottom side), 194 nets.

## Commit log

2018-01-29 Power layout single driver done
    [schematic.kicad_pcb]
2018-01-29 Most power routed to drivers
    [schematic.kicad_pcb]
2018-01-30 Moved capacitors for better power connection
    [schematic.kicad_pcb]
2018-01-30 More driver routing
    [schematic.kicad_pcb]
2018-01-30 main power plains routed
    [schematic.kicad_pcb]
2018-01-30 Started initial spi routing
    [schematic.kicad_pcb]
2018-01-30 routed 3.3V power and start re arange signals
    [Mosfet.sch, aref.sch, motor.sch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]
2018-01-30 Reassigned signals to driver for easier routing
    [schematic.kicad_pcb, schematic.sch]
2018-01-30 Routed signals to E driver
    [schematic.kicad_pcb]
2018-01-30 Routed all control signals to drivers
    [schematic.kicad_pcb, schematic.sch]
2018-01-30 More routing done
    [schematic.kicad_pcb]
2018-01-31 Added display headers
    [Mosfet.sch, aref.sch, motor.sch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]
2018-01-31 3.3V to upper area of the board
    [schematic.kicad_pcb]
2018-01-31 Routed current pwm drivers
    [schematic.kicad_pcb, schematic.sch]
2018-01-31 Routed signals to pi connector
    [orangepi.sch, schematic.kicad_pcb, schematic.sch]
2018-01-31 Saved layout
    [schematic.kicad_pcb]
2018-02-01 Routed thermal sensors
    [schematic.kicad_pcb]
2018-02-03 Finished routing
    [schematic.kicad_pcb]
2018-02-03 Added GPIO header
    [Mosfet.sch, aref.sch, motor.sch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]
2018-02-03 Route gpio header
    [schematic.kicad_pcb]
2018-02-04 Fixed C93 footprint
    [Mosfet.sch, schematic.kicad_pcb]
2018-02-04 Changed footprint size of some capacitors
    [motor.sch, power.sch, schematic.kicad_pcb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]
2018-02-04 updated footprint bat54sw
    [motor.sch, schematic.kicad_pcb, sensors.sch]
2018-02-04 Updated inductor footprint
    [power.sch, schematic.kicad_pcb]
2018-02-04 Fixed inductor footprint
    [power.sch, schematic.kicad_pcb]
2018-02-04 Switch orange pi to raspberry pi zero w because the price difference is small
    [Mosfet.sch, aref.sch, motor.sch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]
2018-04-09 Added bom
    [schematic.ods]
2018-04-16 Update regulators
    [power.sch, schematic.kicad_pcb]
2018-04-19 Updated to kicad 5.0.0
    [Mosfet.sch, aref.sch, motor.sch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]
2018-04-22 Revert "Updated to kicad 5.0.0"
    This reverts commit 6c14fa6c8e6361c9b9ee4065803a5a63755fc6a7.
    [Mosfet.sch, aref.sch, motor.sch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]
2018-04-23 Removed some components
    [Mosfet.sch, aref.sch, motor.sch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]
2018-04-23 Added logo's and stm32 capacitors
    [Mosfet.sch, aref.sch, motor.sch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]
2018-04-23 Added ground pours to internal layers
    [schematic.kicad_pcb]
2018-04-23 Saved schematic
    [schematic.sch]
2018-08-16 Updated to kicad v5
    [Mosfet.sch, aref.sch, motor.sch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]
